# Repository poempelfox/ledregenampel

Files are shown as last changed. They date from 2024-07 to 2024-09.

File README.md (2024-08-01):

# LED-Regen-Ampel

## Intro

This is a small project that contains hardware design and
firmware for a small traffic-light-style display that shows
whether you can leave the house without getting wet. As it
utilizes regenampel.de to get the prediction, this is pretty
much useless outside of germany, which is why the rest of
the description is in german.

Haupt-Ziel dieses Projekts war es, mal eine Platine mit
richtig vielen LEDs drauf zu designen, um sie dann von einem
guenstigen Chinesischen Prototypenfertiger (JLCPCB) anfertigen
zu lassen.
Da ich ein Fan der [Regenampel](https://regenampel.de)
bin, kam die Idee auf, eine aus ganz vielen LEDs bestehende
Regenampel zu konstruieren, in einer Groesse die man bequem
neben die Wohnungstuer oder auch die Tuer des [ZAM](https://zam.haus)
haengen kann.

## Hardware Beschreibung Grob-Uebersicht

* ca. 21 x 7,5 cm grosse Platine
* Rot / Gelb / Gruen bestehend aus je 51 in konzentrischen Kreisen
  angeordneten LEDs (keine superhellen, generische in 0805 Gehaeuse),
  Durchmesser 5 cm.
* kleines OLED-Display unter der Ampel, um den Zusatztext den die
  Regenampel in manchen Situationen liefert (Beispiel: "Noch 20 Minuten
  starker Niederschlag") anzeigen zu koennen.
* Ein WaveShare ESP32-C3-Zero dient als zentrale Steuerung. Er wird
  auf die Rueckseite geloetet.
* Der ESP32-C3 steuert die LEDs ueber je einen MOSFET pro Farbe
  mit einem dedizierten I/O-Pin pro Farbe. Die Helligkeit kann dabei
  fuer jede Farbe einzeln ueber PWM mit 4096 Stufen geregelt werden.
  Das OLED wird ueber I2C angesprochen.
* momentaner Status: Hardware wurde geliefert und funktioniert zumindest
  teilweise.

## Hardware-Beschreibung Detail

Die Platine wurde in KiCad entworfen.
Die KiCad-Dateien finden sich im Unterverzeichnis [kicad/](kicad/).

Um die Platine nachbauen zu lassen, braucht man moeglicherweise
nichtmal KiCad zu oeffnen: Denn im Unterverzeichnis
[kicad/ledregenampel/jlcpcb/production_files/](kicad/ledregenampel/jlcpcb/production_files/)
finden sich die drei Dateien, die JLCPCB benoetigt um die Platine
zu fertigen: Das gerber-.zip, die BOM (Bill Of Materials), und das
CPL (Component PLacement). Verwendet wurde das, was im Juli 2024
dort auf Lager war. Solltet ihr zu einem spaeteren Zeitpunkt versuchen
das auch fertigen zu lassen, koennte es natuerlich sein dass Teile
nicht auf Lager sind und ersetzt werden muessen. Anders formuliert: YMMV.

Neben der gefertigten Platine sind nur zwei zusaetzliche Teile
notwendig:

* WaveShare ESP32-C3-Zero. Ein Microcontroller mit castellated mounting
  holes, so dass man ihn ohne Gefummel mit Buchsen- und Stiftleisten
  einfach auf die Rueckseite der Platine loeten kann. Der C3 ist zum
  Zeitpunkt dieses Projekts einer der kleinsten (und billigsten)
  Microcontroller die Espressif anbietet, fuer die ihm hier zugedachten
  Aufgaben aber immer noch deutlich ueberdimensioniert. Auf der
  Waveshare-Platine befindet sich u.a. eine USB-C-Buchse und ein
  Spannungsregler (Linearregler :-/) fuer die 3.3V.
* [Ein von TinyTronics bezogenes 2.08 inch OLED-Display mit 256x64 Pixeln](https://www.tinytronics.nl/en/displays/oled/2.08-inch-oled-display-256*64-pixels-white-i2c). Ich hatte
  ernsthafte Probleme, ein meinen Anforderungen nach "nicht winzig, I2C,
  extra-wide, 3.3V" entsprechendes Display zu finden, das war eines der
  wenigen passenden Angebote. Es handelt sich um ein Display
  des zumindest mir voellig unbekannten Herstellers "ZHONGJINGYUAN"
  mit einem SHT1122 Controller. Das Display wird ueber I2C
  angesprochen. Es wird auf die Vorderseite der LED-Regenampel-
  Platine geloetet.

Die USB-C-Buchse auf dem ESP32-Board ist der normale Weg, um
das Projekt mit Strom zu versorgen. USB-Power und "5V" Schiene
auf der Platine sind dabei einfach durchverbunden, d.h. es darf
falls auf andere Weise 5V eingespeist werden KEINESFALLS
gleichzeitig USB-C verbunden werden. Es ist ausserdem zu
beachten, dass der erwartete Stromverbrauch einer einzigen
Ampelfarbe bei 100% Helligkeit um 1A liegt. Es empfiehlt sich
also nicht, mehrere Ampelfarben gleichzeitig mit hoher
Helligkeit leuchten zu lassen.

Uebrigens sind 100% Helligkeit generell nicht der intendierte
Betriebsmodus. Mal abgesehen von dem geringfuegigen Problem,
dass das vermutlich den Betrachter der Ampel blind machen
wuerde, ist auch die dabei entstehende Abwaerme enorm -
die Platine wuerde wahrscheinlich recht schnell ueberhitzen.
"Normal" ist PWM mit unter 20% duty cycle...

## Hardware - known bugs

* Der ESP32-C3 wurde bei ersten Vorabtests alleine unangenehm
  heiss. Das ist laut "Internet" normal, und laut Specs darf
  der Chip auch bis zu 105 Grad. Nach dem aufloeten der Waveshare-
  Platine auf die grosse Platine scheint jedoch die
  Waerme sehr gut an die grosse Platine abgegeben zu werden,
  es ist kein nennenswerter Waermeherd mehr feststellbar.
* Die Loecher fuer das I2C-Display sind etwas arg klein geraten.
  Es passt gerade noch so, hat aber merklichen Widerstand beim
  einstecken der Display-Pins, und ist unschoen zu loeten.
  Dieser Fehler wurde im KiCad-.pcb-File bereits behoben.

## Firmware

* basiert auf der foxesptemp-Firmware.
* hat ein Admin-Webinterface, ueber das der angezeigte Ort (bzw. Weg)
  und die Helligkeit der Ampelfarben eingestellt werden kann.
* Hinweis: Der C3 wird anders programmiert als die meisten
  ESPs, es gibt naemlich keinen USB-seriell-Adapter auf der
  winzigen Platine. Stattdessen muss man: USB mit dem Rechner
  verbinden, dann den "Boot"-Knopf gedrueckt halten, dann
  kurz "Reset" druecken, dann kann man nach ein paar
  Sekunden "Boot" wieder loslassen. Dadurch geht der Chip
  in den Programmiermodus, der Bootloader emuliert einen
  USB-Seriell-Adapter, und man kann ihn wie gewohnt
  ueber idf.py flashen. Auch den Reset am Ende des Flashens
  muss man allerdings manuell machen, wieder ueber
  Knopfdruck. Gluecklicherweise muss man dieses komplexe
  Procedere nur ein mal zur Erstbefuellung durchfuehren:
  Die ledregenampel-firmware unterstuetzt Online-Firmware-
  Update ueber ihr Webinterface...

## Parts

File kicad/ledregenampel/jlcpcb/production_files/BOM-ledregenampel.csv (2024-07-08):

Comment | Designator | Footprint | LCSC
C1 | 100nF | C_0402_1005Metric | C1525 | 26786529 | 0 | 0
C2 | 100uF | C_1206_3216Metric | C15008 | 1087743 | 0 | 0
C3 | 100uF | C_1206_3216Metric | C15008 | 1087743 | 0 | 0
C4 | 100uF | C_1206_3216Metric | C15008 | 1087743 | 0 | 0
C5 | 100uF | C_1206_3216Metric | C15008 | 1087743 | 0 | 0
C6 | 100nF | C_0402_1005Metric | C1525 | 26786529 | 0 | 0
D1 | LED G | LED_0805_2012Metric | C688883 | 15123 | 0 | 0
D10 | LED G | LED_0805_2012Metric | C688883 | 15123 | 0 | 0
D100 | LED Y | LED_0805_2012Metric | C779458 | 3875 | 0 | 0
D101 | LED Y | LED_0805_2012Metric | C779458 | 3875 | 0 | 0
D102 | LED Y | LED_0805_2012Metric | C779458 | 3875 | 0 | 0
D103 | LED R | LED_0805_2012Metric | C688884 | 23736 | 0 | 0
D104 | LED R | LED_0805_2012Metric | C688884 | 23736 | 0 | 0
D105 | LED R | LED_0805_2012Metric | C688884 | 23736 | 0 | 0
D106 | LED R | LED_0805_2012Metric | C688884 | 23736 | 0 | 0
D107 | LED R | LED_0805_2012Metric | C688884 | 23736 | 0 | 0
D108 | LED R | LED_0805_2012Metric | C688884 | 23736 | 0 | 0
D109 | LED R | LED_0805_2012Metric | C688884 | 23736 | 0 | 0
D11 | LED G | LED_0805_2012Metric | C688883 | 15123 | 0 | 0
D110 | LED R | LED_0805_2012Metric | C688884 | 23736 | 0 | 0
D111 | LED R | LED_0805_2012Metric | C688884 | 23736 | 0 | 0
D112 | LED R | LED_0805_2012Metric | C688884 | 23736 | 0 | 0
D113 | LED R | LED_0805_2012Metric | C688884 | 23736 | 0 | 0
D114 | LED R | LED_0805_2012Metric | C688884 | 23736 | 0 | 0
D115 | LED R | LED_0805_2012Metric | C688884 | 23736 | 0 | 0
D116 | LED R | LED_0805_2012Metric | C688884 | 23736 | 0 | 0
D117 | LED R | LED_0805_2012Metric | C688884 | 23736 | 0 | 0
D118 | LED R | LED_0805_2012Metric | C688884 | 23736 | 0 | 0
D119 | LED R | LED_0805_2012Metric | C688884 | 23736 | 0 | 0
D12 | LED G | LED_0805_2012Metric | C688883 | 15123 | 0 | 0
D120 | LED R | LED_0805_2012Metric | C688884 | 23736 | 0 | 0
D121 | LED R | LED_0805_2012Metric | C688884 | 23736 | 0 | 0
D122 | LED R | LED_0805_2012Metric | C688884 | 23736 | 0 | 0
D123 | LED R | LED_0805_2012Metric | C688884 | 23736 | 0 | 0
D124 | LED R | LED_0805_2012Metric | C688884 | 23736 | 0 | 0
D125 | LED R | LED_0805_2012Metric | C688884 | 23736 | 0 | 0
D126 | LED R | LED_0805_2012Metric | C688884 | 23736 | 0 | 0
D127 | LED R | LED_0805_2012Metric | C688884 | 23736 | 0 | 0
D128 | LED R | LED_0805_2012Metric | C688884 | 23736 | 0 | 0
D129 | LED R | LED_0805_2012Metric | C688884 | 23736 | 0 | 0
D13 | LED G | LED_0805_2012Metric | C688883 | 15123 | 0 | 0
D130 | LED R | LED_0805_2012Metric | C688884 | 23736 | 0 | 0
D131 | LED R | LED_0805_2012Metric | C688884 | 23736 | 0 | 0
D132 | LED R | LED_0805_2012Metric | C688884 | 23736 | 0 | 0
D133 | LED R | LED_0805_2012Metric | C688884 | 23736 | 0 | 0
D134 | LED R | LED_0805_2012Metric | C688884 | 23736 | 0 | 0
D135 | LED R | LED_0805_2012Metric | C688884 | 23736 | 0 | 0
D136 | LED R | LED_0805_2012Metric | C688884 | 23736 | 0 | 0
D137 | LED R | LED_0805_2012Metric | C688884 | 23736 | 0 | 0
D138 | LED R | LED_0805_2012Metric | C688884 | 23736 | 0 | 0
D139 | LED R | LED_0805_2012Metric | C688884 | 23736 | 0 | 0
D14 | LED G | LED_0805_2012Metric | C688883 | 15123 | 0 | 0
D140 | LED R | LED_0805_2012Metric | C688884 | 23736 | 0 | 0
D141 | LED R | LED_0805_2012Metric | C688884 | 23736 | 0 | 0
D142 | LED R | LED_0805_2012Metric | C688884 | 23736 | 0 | 0
D143 | LED R | LED_0805_2012Metric | C688884 | 23736 | 0 | 0
D144 | LED R | LED_0805_2012Metric | C688884 | 23736 | 0 | 0
D145 | LED R | LED_0805_2012Metric | C688884 | 23736 | 0 | 0
D146 | LED R | LED_0805_2012Metric | C688884 | 23736 | 0 | 0
D147 | LED R | LED_0805_2012Metric | C688884 | 23736 | 0 | 0
D148 | LED R | LED_0805_2012Metric | C688884 | 23736 | 0 | 0
D149 | LED R | LED_0805_2012Metric | C688884 | 23736 | 0 | 0
D15 | LED G | LED_0805_2012Metric | C688883 | 15123 | 0 | 0
D150 | LED R | LED_0805_2012Metric | C688884 | 23736 | 0 | 0
D151 | LED R | LED_0805_2012Metric | C688884 | 23736 | 0 | 0
D152 | LED R | LED_0805_2012Metric | C688884 | 23736 | 0 | 0
D153 | LED R | LED_0805_2012Metric | C688884 | 23736 | 0 | 0
D16 | LED G | LED_0805_2012Metric | C688883 | 15123 | 0 | 0
D17 | LED G | LED_0805_2012Metric | C688883 | 15123 | 0 | 0
D18 | LED G | LED_0805_2012Metric | C688883 | 15123 | 0 | 0
D19 | LED G | LED_0805_2012Metric | C688883 | 15123 | 0 | 0
D2 | LED G | LED_0805_2012Metric | C688883 | 15123 | 0 | 0
D20 | LED G | LED_0805_2012Metric | C688883 | 15123 | 0 | 0
D21 | LED G | LED_0805_2012Metric | C688883 | 15123 | 0 | 0
D22 | LED G | LED_0805_2012Metric | C688883 | 15123 | 0 | 0
D23 | LED G | LED_0805_2012Metric | C688883 | 15123 | 0 | 0
D24 | LED G | LED_0805_2012Metric | C688883 | 15123 | 0 | 0
D25 | LED G | LED_0805_2012Metric | C688883 | 15123 | 0 | 0
D26 | LED G | LED_0805_2012Metric | C688883 | 15123 | 0 | 0
D27 | LED G | LED_0805_2012Metric | C688883 | 15123 | 0 | 0
D28 | LED G | LED_0805_2012Metric | C688883 | 15123 | 0 | 0
D29 | LED G | LED_0805_2012Metric | C688883 | 15123 | 0 | 0
D3 | LED G | LED_0805_2012Metric | C688883 | 15123 | 0 | 0
D30 | LED G | LED_0805_2012Metric | C688883 | 15123 | 0 | 0
D31 | LED G | LED_0805_2012Metric | C688883 | 15123 | 0 | 0
D32 | LED G | LED_0805_2012Metric | C688883 | 15123 | 0 | 0
D33 | LED G | LED_0805_2012Metric | C688883 | 15123 | 0 | 0
D34 | LED G | LED_0805_2012Metric | C688883 | 15123 | 0 | 0
D35 | LED G | LED_0805_2012Metric | C688883 | 15123 | 0 | 0
D36 | LED G | LED_0805_2012Metric | C688883 | 15123 | 0 | 0
D37 | LED G | LED_0805_2012Metric | C688883 | 15123 | 0 | 0
D38 | LED G | LED_0805_2012Metric | C688883 | 15123 | 0 | 0
D39 | LED G | LED_0805_2012Metric | C688883 | 15123 | 0 | 0
D4 | LED G | LED_0805_2012Metric | C688883 | 15123 | 0 | 0
D40 | LED G | LED_0805_2012Metric | C688883 | 15123 | 0 | 0
D41 | LED G | LED_0805_2012Metric | C688883 | 15123 | 0 | 0
D42 | LED G | LED_0805_2012Metric | C688883 | 15123 | 0 | 0
D43 | LED G | LED_0805_2012Metric | C688883 | 15123 | 0 | 0
D44 | LED G | LED_0805_2012Metric | C688883 | 15123 | 0 | 0
D45 | LED G | LED_0805_2012Metric | C688883 | 15123 | 0 | 0
D46 | LED G | LED_0805_2012Metric | C688883 | 15123 | 0 | 0
D47 | LED G | LED_0805_2012Metric | C688883 | 15123 | 0 | 0
D48 | LED G | LED_0805_2012Metric | C688883 | 15123 | 0 | 0
D49 | LED G | LED_0805_2012Metric | C688883 | 15123 | 0 | 0
D5 | LED G | LED_0805_2012Metric | C688883 | 15123 | 0 | 0
D50 | LED G | LED_0805_2012Metric | C688883 | 15123 | 0 | 0
D51 | LED G | LED_0805_2012Metric | C688883 | 15123 | 0 | 0
D52 | LED Y | LED_0805_2012Metric | C779458 | 3875 | 0 | 0
D53 | LED Y | LED_0805_2012Metric | C779458 | 3875 | 0 | 0
D54 | LED Y | LED_0805_2012Metric | C779458 | 3875 | 0 | 0
D55 | LED Y | LED_0805_2012Metric | C779458 | 3875 | 0 | 0
D56 | LED Y | LED_0805_2012Metric | C779458 | 3875 | 0 | 0
D57 | LED Y | LED_0805_2012Metric | C779458 | 3875 | 0 | 0
D58 | LED Y | LED_0805_2012Metric | C779458 | 3875 | 0 | 0
D59 | LED Y | LED_0805_2012Metric | C779458 | 3875 | 0 | 0
D6 | LED G | LED_0805_2012Metric | C688883 | 15123 | 0 | 0
D60 | LED Y | LED_0805_2012Metric | C779458 | 3875 | 0 | 0
D61 | LED Y | LED_0805_2012Metric | C779458 | 3875 | 0 | 0
D62 | LED Y | LED_0805_2012Metric | C779458 | 3875 | 0 | 0
D63 | LED Y | LED_0805_2012Metric | C779458 | 3875 | 0 | 0
D64 | LED Y | LED_0805_2012Metric | C779458 | 3875 | 0 | 0
D65 | LED Y | LED_0805_2012Metric | C779458 | 3875 | 0 | 0
D66 | LED Y | LED_0805_2012Metric | C779458 | 3875 | 0 | 0
D67 | LED Y | LED_0805_2012Metric | C779458 | 3875 | 0 | 0
D68 | LED Y | LED_0805_2012Metric | C779458 | 3875 | 0 | 0
D69 | LED Y | LED_0805_2012Metric | C779458 | 3875 | 0 | 0
D7 | LED G | LED_0805_2012Metric | C688883 | 15123 | 0 | 0
D70 | LED Y | LED_0805_2012Metric | C779458 | 3875 | 0 | 0
D71 | LED Y | LED_0805_2012Metric | C779458 | 3875 | 0 | 0
D72 | LED Y | LED_0805_2012Metric | C779458 | 3875 | 0 | 0
D73 | LED Y | LED_0805_2012Metric | C779458 | 3875 | 0 | 0
D74 | LED Y | LED_0805_2012Metric | C779458 | 3875 | 0 | 0
D75 | LED Y | LED_0805_2012Metric | C779458 | 3875 | 0 | 0
D76 | LED Y | LED_0805_2012Metric | C779458 | 3875 | 0 | 0
D77 | LED Y | LED_0805_2012Metric | C779458 | 3875 | 0 | 0
D78 | LED Y | LED_0805_2012Metric | C779458 | 3875 | 0 | 0
D79 | LED Y | LED_0805_2012Metric | C779458 | 3875 | 0 | 0
D8 | LED G | LED_0805_2012Metric | C688883 | 15123 | 0 | 0
D80 | LED Y | LED_0805_2012Metric | C779458 | 3875 | 0 | 0
D81 | LED Y | LED_0805_2012Metric | C779458 | 3875 | 0 | 0
D82 | LED Y | LED_0805_2012Metric | C779458 | 3875 | 0 | 0
D83 | LED Y | LED_0805_2012Metric | C779458 | 3875 | 0 | 0
D84 | LED Y | LED_0805_2012Metric | C779458 | 3875 | 0 | 0
D85 | LED Y | LED_0805_2012Metric | C779458 | 3875 | 0 | 0
D86 | LED Y | LED_0805_2012Metric | C779458 | 3875 | 0 | 0
D87 | LED Y | LED_0805_2012Metric | C779458 | 3875 | 0 | 0
D88 | LED Y | LED_0805_2012Metric | C779458 | 3875 | 0 | 0
D89 | LED Y | LED_0805_2012Metric | C779458 | 3875 | 0 | 0
D9 | LED G | LED_0805_2012Metric | C688883 | 15123 | 0 | 0
D90 | LED Y | LED_0805_2012Metric | C779458 | 3875 | 0 | 0
D91 | LED Y | LED_0805_2012Metric | C779458 | 3875 | 0 | 0
D92 | LED Y | LED_0805_2012Metric | C779458 | 3875 | 0 | 0
D93 | LED Y | LED_0805_2012Metric | C779458 | 3875 | 0 | 0
D94 | LED Y | LED_0805_2012Metric | C779458 | 3875 | 0 | 0
D95 | LED Y | LED_0805_2012Metric | C779458 | 3875 | 0 | 0
D96 | LED Y | LED_0805_2012Metric | C779458 | 3875 | 0 | 0
D97 | LED Y | LED_0805_2012Metric | C779458 | 3875 | 0 | 0
D98 | LED Y | LED_0805_2012Metric | C779458 | 3875 | 0 | 0
D99 | LED Y | LED_0805_2012Metric | C779458 | 3875 | 0 | 0
Q1 | AO3400A | SOT-23 | C20917 | 628525 | 0 | 0
Q2 | AO3400A | SOT-23 | C20917 | 628525 | 0 | 0
Q3 | AO3400A | SOT-23 | C20917 | 628525 | 0 | 0
R1 | 120Ω | R_0402_modsilkscreen | C25079 | 547006 | 0 | 0
R10 | 120Ω | R_0402_modsilkscreen | C25079 | 547006 | 0 | 0
R100 | 150Ω | R_0402_modsilkscreen | C25143 | 39000 | 0 | 0
R101 | 150Ω | R_0402_modsilkscreen | C25143 | 39000 | 0 | 0
R102 | 150Ω | R_0402_modsilkscreen | C25143 | 39000 | 0 | 0
R103 | 150Ω | R_0402_modsilkscreen | C25143 | 39000 | 0 | 0
R104 | 150Ω | R_0402_modsilkscreen | C25143 | 39000 | 0 | 0
R105 | 150Ω | R_0402_modsilkscreen | C25143 | 39000 | 0 | 0
R106 | 150Ω | R_0402_modsilkscreen | C25143 | 39000 | 0 | 0
R107 | 150Ω | R_0402_modsilkscreen | C25143 | 39000 | 0 | 0
R108 | 150Ω | R_0402_modsilkscreen | C25143 | 39000 | 0 | 0
R109 | 150Ω | R_0402_modsilkscreen | C25143 | 39000 | 0 | 0
R11 | 120Ω | R_0402_modsilkscreen | C25079 | 547006 | 0 | 0
R110 | 150Ω | R_0402_modsilkscreen | C25143 | 39000 | 0 | 0
R111 | 150Ω | R_0402_modsilkscreen | C25143 | 39000 | 0 | 0
R112 | 150Ω | R_0402_modsilkscreen | C25143 | 39000 | 0 | 0
R113 | 150Ω | R_0402_modsilkscreen | C25143 | 39000 | 0 | 0
R114 | 150Ω | R_0402_modsilkscreen | C25143 | 39000 | 0 | 0
R115 | 150Ω | R_0402_modsilkscreen | C25143 | 39000 | 0 | 0
R116 | 150Ω | R_0402_modsilkscreen | C25143 | 39000 | 0 | 0
R117 | 150Ω | R_0402_modsilkscreen | C25143 | 39000 | 0 | 0
R118 | 150Ω | R_0402_modsilkscreen | C25143 | 39000 | 0 | 0
R119 | 150Ω | R_0402_modsilkscreen | C25143 | 39000 | 0 | 0
R12 | 120Ω | R_0402_modsilkscreen | C25079 | 547006 | 0 | 0
R120 | 150Ω | R_0402_modsilkscreen | C25143 | 39000 | 0 | 0
R121 | 150Ω | R_0402_modsilkscreen | C25143 | 39000 | 0 | 0
R122 | 150Ω | R_0402_modsilkscreen | C25143 | 39000 | 0 | 0
R123 | 150Ω | R_0402_modsilkscreen | C25143 | 39000 | 0 | 0
R124 | 150Ω | R_0402_modsilkscreen | C25143 | 39000 | 0 | 0
R125 | 150Ω | R_0402_modsilkscreen | C25143 | 39000 | 0 | 0
R126 | 150Ω | R_0402_modsilkscreen | C25143 | 39000 | 0 | 0
R127 | 150Ω | R_0402_modsilkscreen | C25143 | 39000 | 0 | 0
R128 | 150Ω | R_0402_modsilkscreen | C25143 | 39000 | 0 | 0
R129 | 150Ω | R_0402_modsilkscreen | C25143 | 39000 | 0 | 0
R13 | 120Ω | R_0402_modsilkscreen | C25079 | 547006 | 0 | 0
R130 | 150Ω | R_0402_modsilkscreen | C25143 | 39000 | 0 | 0
R131 | 150Ω | R_0402_modsilkscreen | C25143 | 39000 | 0 | 0
R132 | 150Ω | R_0402_modsilkscreen | C25143 | 39000 | 0 | 0
R133 | 150Ω | R_0402_modsilkscreen | C25143 | 39000 | 0 | 0
R134 | 150Ω | R_0402_modsilkscreen | C25143 | 39000 | 0 | 0
R135 | 150Ω | R_0402_modsilkscreen | C25143 | 39000 | 0 | 0
R136 | 150Ω | R_0402_modsilkscreen | C25143 | 39000 | 0 | 0
R137 | 150Ω | R_0402_modsilkscreen | C25143 | 39000 | 0 | 0
R138 | 150Ω | R_0402_modsilkscreen | C25143 | 39000 | 0 | 0
R139 | 150Ω | R_0402_modsilkscreen | C25143 | 39000 | 0 | 0
R14 | 120Ω | R_0402_modsilkscreen | C25079 | 547006 | 0 | 0
R140 | 150Ω | R_0402_modsilkscreen | C25143 | 39000 | 0 | 0
R141 | 150Ω | R_0402_modsilkscreen | C25143 | 39000 | 0 | 0
R142 | 150Ω | R_0402_modsilkscreen | C25143 | 39000 | 0 | 0
R143 | 150Ω | R_0402_modsilkscreen | C25143 | 39000 | 0 | 0
R144 | 150Ω | R_0402_modsilkscreen | C25143 | 39000 | 0 | 0
R145 | 150Ω | R_0402_modsilkscreen | C25143 | 39000 | 0 | 0
R146 | 150Ω | R_0402_modsilkscreen | C25143 | 39000 | 0 | 0
R147 | 150Ω | R_0402_modsilkscreen | C25143 | 39000 | 0 | 0
R148 | 150Ω | R_0402_modsilkscreen | C25143 | 39000 | 0 | 0
R149 | 150Ω | R_0402_modsilkscreen | C25143 | 39000 | 0 | 0
R15 | 120Ω | R_0402_modsilkscreen | C25079 | 547006 | 0 | 0
R150 | 150Ω | R_0402_modsilkscreen | C25143 | 39000 | 0 | 0
R151 | 150Ω | R_0402_modsilkscreen | C25143 | 39000 | 0 | 0
R152 | 150Ω | R_0402_modsilkscreen | C25143 | 39000 | 0 | 0
R153 | 150Ω | R_0402_modsilkscreen | C25143 | 39000 | 0 | 0
R154 | 33Ω | R_0402_modsilkscreen | C25105 | 2829282 | 0 | 0
R155 | 33Ω | R_0402_modsilkscreen | C25105 | 2829282 | 0 | 0
R156 | 33Ω | R_0402_modsilkscreen | C25105 | 2829282 | 0 | 0
R157 | 1MΩ | R_0402_modsilkscreen | C26083 | 2594408 | 0 | 0
R158 | 1MΩ | R_0402_modsilkscreen | C26083 | 2594408 | 0 | 0
R159 | 1MΩ | R_0402_modsilkscreen | C26083 | 2594408 | 0 | 0
R16 | 120Ω | R_0402_modsilkscreen | C25079 | 547006 | 0 | 0
R17 | 120Ω | R_0402_modsilkscreen | C25079 | 547006 | 0 | 0
R18 | 120Ω | R_0402_modsilkscreen | C25079 | 547006 | 0 | 0
R19 | 120Ω | R_0402_modsilkscreen | C25079 | 547006 | 0 | 0
R2 | 120Ω | R_0402_modsilkscreen | C25079 | 547006 | 0 | 0
R20 | 120Ω | R_0402_modsilkscreen | C25079 | 547006 | 0 | 0
R21 | 120Ω | R_0402_modsilkscreen | C25079 | 547006 | 0 | 0
R22 | 120Ω | R_0402_modsilkscreen | C25079 | 547006 | 0 | 0
R23 | 120Ω | R_0402_modsilkscreen | C25079 | 547006 | 0 | 0
R24 | 120Ω | R_0402_modsilkscreen | C25079 | 547006 | 0 | 0
R25 | 120Ω | R_0402_modsilkscreen | C25079 | 547006 | 0 | 0
R26 | 120Ω | R_0402_modsilkscreen | C25079 | 547006 | 0 | 0
R27 | 120Ω | R_0402_modsilkscreen | C25079 | 547006 | 0 | 0
R28 | 120Ω | R_0402_modsilkscreen | C25079 | 547006 | 0 | 0
R29 | 120Ω | R_0402_modsilkscreen | C25079 | 547006 | 0 | 0
R3 | 120Ω | R_0402_modsilkscreen | C25079 | 547006 | 0 | 0
R30 | 120Ω | R_0402_modsilkscreen | C25079 | 547006 | 0 | 0
R31 | 120Ω | R_0402_modsilkscreen | C25079 | 547006 | 0 | 0
R32 | 120Ω | R_0402_modsilkscreen | C25079 | 547006 | 0 | 0
R33 | 120Ω | R_0402_modsilkscreen | C25079 | 547006 | 0 | 0
R34 | 120Ω | R_0402_modsilkscreen | C25079 | 547006 | 0 | 0
R35 | 120Ω | R_0402_modsilkscreen | C25079 | 547006 | 0 | 0
R36 | 120Ω | R_0402_modsilkscreen | C25079 | 547006 | 0 | 0
R37 | 120Ω | R_0402_modsilkscreen | C25079 | 547006 | 0 | 0
R38 | 120Ω | R_0402_modsilkscreen | C25079 | 547006 | 0 | 0
R39 | 120Ω | R_0402_modsilkscreen | C25079 | 547006 | 0 | 0
R4 | 120Ω | R_0402_modsilkscreen | C25079 | 547006 | 0 | 0
R40 | 120Ω | R_0402_modsilkscreen | C25079 | 547006 | 0 | 0
R41 | 120Ω | R_0402_modsilkscreen | C25079 | 547006 | 0 | 0
R42 | 120Ω | R_0402_modsilkscreen | C25079 | 547006 | 0 | 0
R43 | 120Ω | R_0402_modsilkscreen | C25079 | 547006 | 0 | 0
R44 | 120Ω | R_0402_modsilkscreen | C25079 | 547006 | 0 | 0
R45 | 120Ω | R_0402_modsilkscreen | C25079 | 547006 | 0 | 0
R46 | 120Ω | R_0402_modsilkscreen | C25079 | 547006 | 0 | 0
R47 | 120Ω | R_0402_modsilkscreen | C25079 | 547006 | 0 | 0
R48 | 120Ω | R_0402_modsilkscreen | C25079 | 547006 | 0 | 0
R49 | 120Ω | R_0402_modsilkscreen | C25079 | 547006 | 0 | 0
R5 | 120Ω | R_0402_modsilkscreen | C25079 | 547006 | 0 | 0
R50 | 120Ω | R_0402_modsilkscreen | C25079 | 547006 | 0 | 0
R51 | 120Ω | R_0402_modsilkscreen | C25079 | 547006 | 0 | 0
R52 | 150Ω | R_0402_modsilkscreen | C25143 | 39000 | 0 | 0
R53 | 150Ω | R_0402_modsilkscreen | C25143 | 39000 | 0 | 0
R54 | 150Ω | R_0402_modsilkscreen | C25143 | 39000 | 0 | 0
R55 | 150Ω | R_0402_modsilkscreen | C25143 | 39000 | 0 | 0
R56 | 150Ω | R_0402_modsilkscreen | C25143 | 39000 | 0 | 0
R57 | 150Ω | R_0402_modsilkscreen | C25143 | 39000 | 0 | 0
R58 | 150Ω | R_0402_modsilkscreen | C25143 | 39000 | 0 | 0
R59 | 150Ω | R_0402_modsilkscreen | C25143 | 39000 | 0 | 0
R6 | 120Ω | R_0402_modsilkscreen | C25079 | 547006 | 0 | 0
R60 | 150Ω | R_0402_modsilkscreen | C25143 | 39000 | 0 | 0
R61 | 150Ω | R_0402_modsilkscreen | C25143 | 39000 | 0 | 0
R62 | 150Ω | R_0402_modsilkscreen | C25143 | 39000 | 0 | 0
R63 | 150Ω | R_0402_modsilkscreen | C25143 | 39000 | 0 | 0
R64 | 150Ω | R_0402_modsilkscreen | C25143 | 39000 | 0 | 0
R65 | 150Ω | R_0402_modsilkscreen | C25143 | 39000 | 0 | 0
R66 | 150Ω | R_0402_modsilkscreen | C25143 | 39000 | 0 | 0
R67 | 150Ω | R_0402_modsilkscreen | C25143 | 39000 | 0 | 0
R68 | 150Ω | R_0402_modsilkscreen | C25143 | 39000 | 0 | 0
R69 | 150Ω | R_0402_modsilkscreen | C25143 | 39000 | 0 | 0
R7 | 120Ω | R_0402_modsilkscreen | C25079 | 547006 | 0 | 0
R70 | 150Ω | R_0402_modsilkscreen | C25143 | 39000 | 0 | 0
R71 | 150Ω | R_0402_modsilkscreen | C25143 | 39000 | 0 | 0
R72 | 150Ω | R_0402_modsilkscreen | C25143 | 39000 | 0 | 0
R73 | 150Ω | R_0402_modsilkscreen | C25143 | 39000 | 0 | 0
R74 | 150Ω | R_0402_modsilkscreen | C25143 | 39000 | 0 | 0
R75 | 150Ω | R_0402_modsilkscreen | C25143 | 39000 | 0 | 0
R76 | 150Ω | R_0402_modsilkscreen | C25143 | 39000 | 0 | 0
R77 | 150Ω | R_0402_modsilkscreen | C25143 | 39000 | 0 | 0
R78 | 150Ω | R_0402_modsilkscreen | C25143 | 39000 | 0 | 0
R79 | 150Ω | R_0402_modsilkscreen | C25143 | 39000 | 0 | 0
R8 | 120Ω | R_0402_modsilkscreen | C25079 | 547006 | 0 | 0
R80 | 150Ω | R_0402_modsilkscreen | C25143 | 39000 | 0 | 0
R81 | 150Ω | R_0402_modsilkscreen | C25143 | 39000 | 0 | 0
R82 | 150Ω | R_0402_modsilkscreen | C25143 | 39000 | 0 | 0
R83 | 150Ω | R_0402_modsilkscreen | C25143 | 39000 | 0 | 0
R84 | 150Ω | R_0402_modsilkscreen | C25143 | 39000 | 0 | 0
R85 | 150Ω | R_0402_modsilkscreen | C25143 | 39000 | 0 | 0
R86 | 150Ω | R_0402_modsilkscreen | C25143 | 39000 | 0 | 0
R87 | 150Ω | R_0402_modsilkscreen | C25143 | 39000 | 0 | 0
R88 | 150Ω | R_0402_modsilkscreen | C25143 | 39000 | 0 | 0
R89 | 150Ω | R_0402_modsilkscreen | C25143 | 39000 | 0 | 0
R9 | 120Ω | R_0402_modsilkscreen | C25079 | 547006 | 0 | 0
R90 | 150Ω | R_0402_modsilkscreen | C25143 | 39000 | 0 | 0
R91 | 150Ω | R_0402_modsilkscreen | C25143 | 39000 | 0 | 0
R92 | 150Ω | R_0402_modsilkscreen | C25143 | 39000 | 0 | 0
R93 | 150Ω | R_0402_modsilkscreen | C25143 | 39000 | 0 | 0
R94 | 150Ω | R_0402_modsilkscreen | C25143 | 39000 | 0 | 0
R95 | 150Ω | R_0402_modsilkscreen | C25143 | 39000 | 0 | 0
R96 | 150Ω | R_0402_modsilkscreen | C25143 | 39000 | 0 | 0
R97 | 150Ω | R_0402_modsilkscreen | C25143 | 39000 | 0 | 0
R98 | 150Ω | R_0402_modsilkscreen | C25143 | 39000 | 0 | 0
R99 | 150Ω | R_0402_modsilkscreen | C25143 | 39000 | 0 | 0

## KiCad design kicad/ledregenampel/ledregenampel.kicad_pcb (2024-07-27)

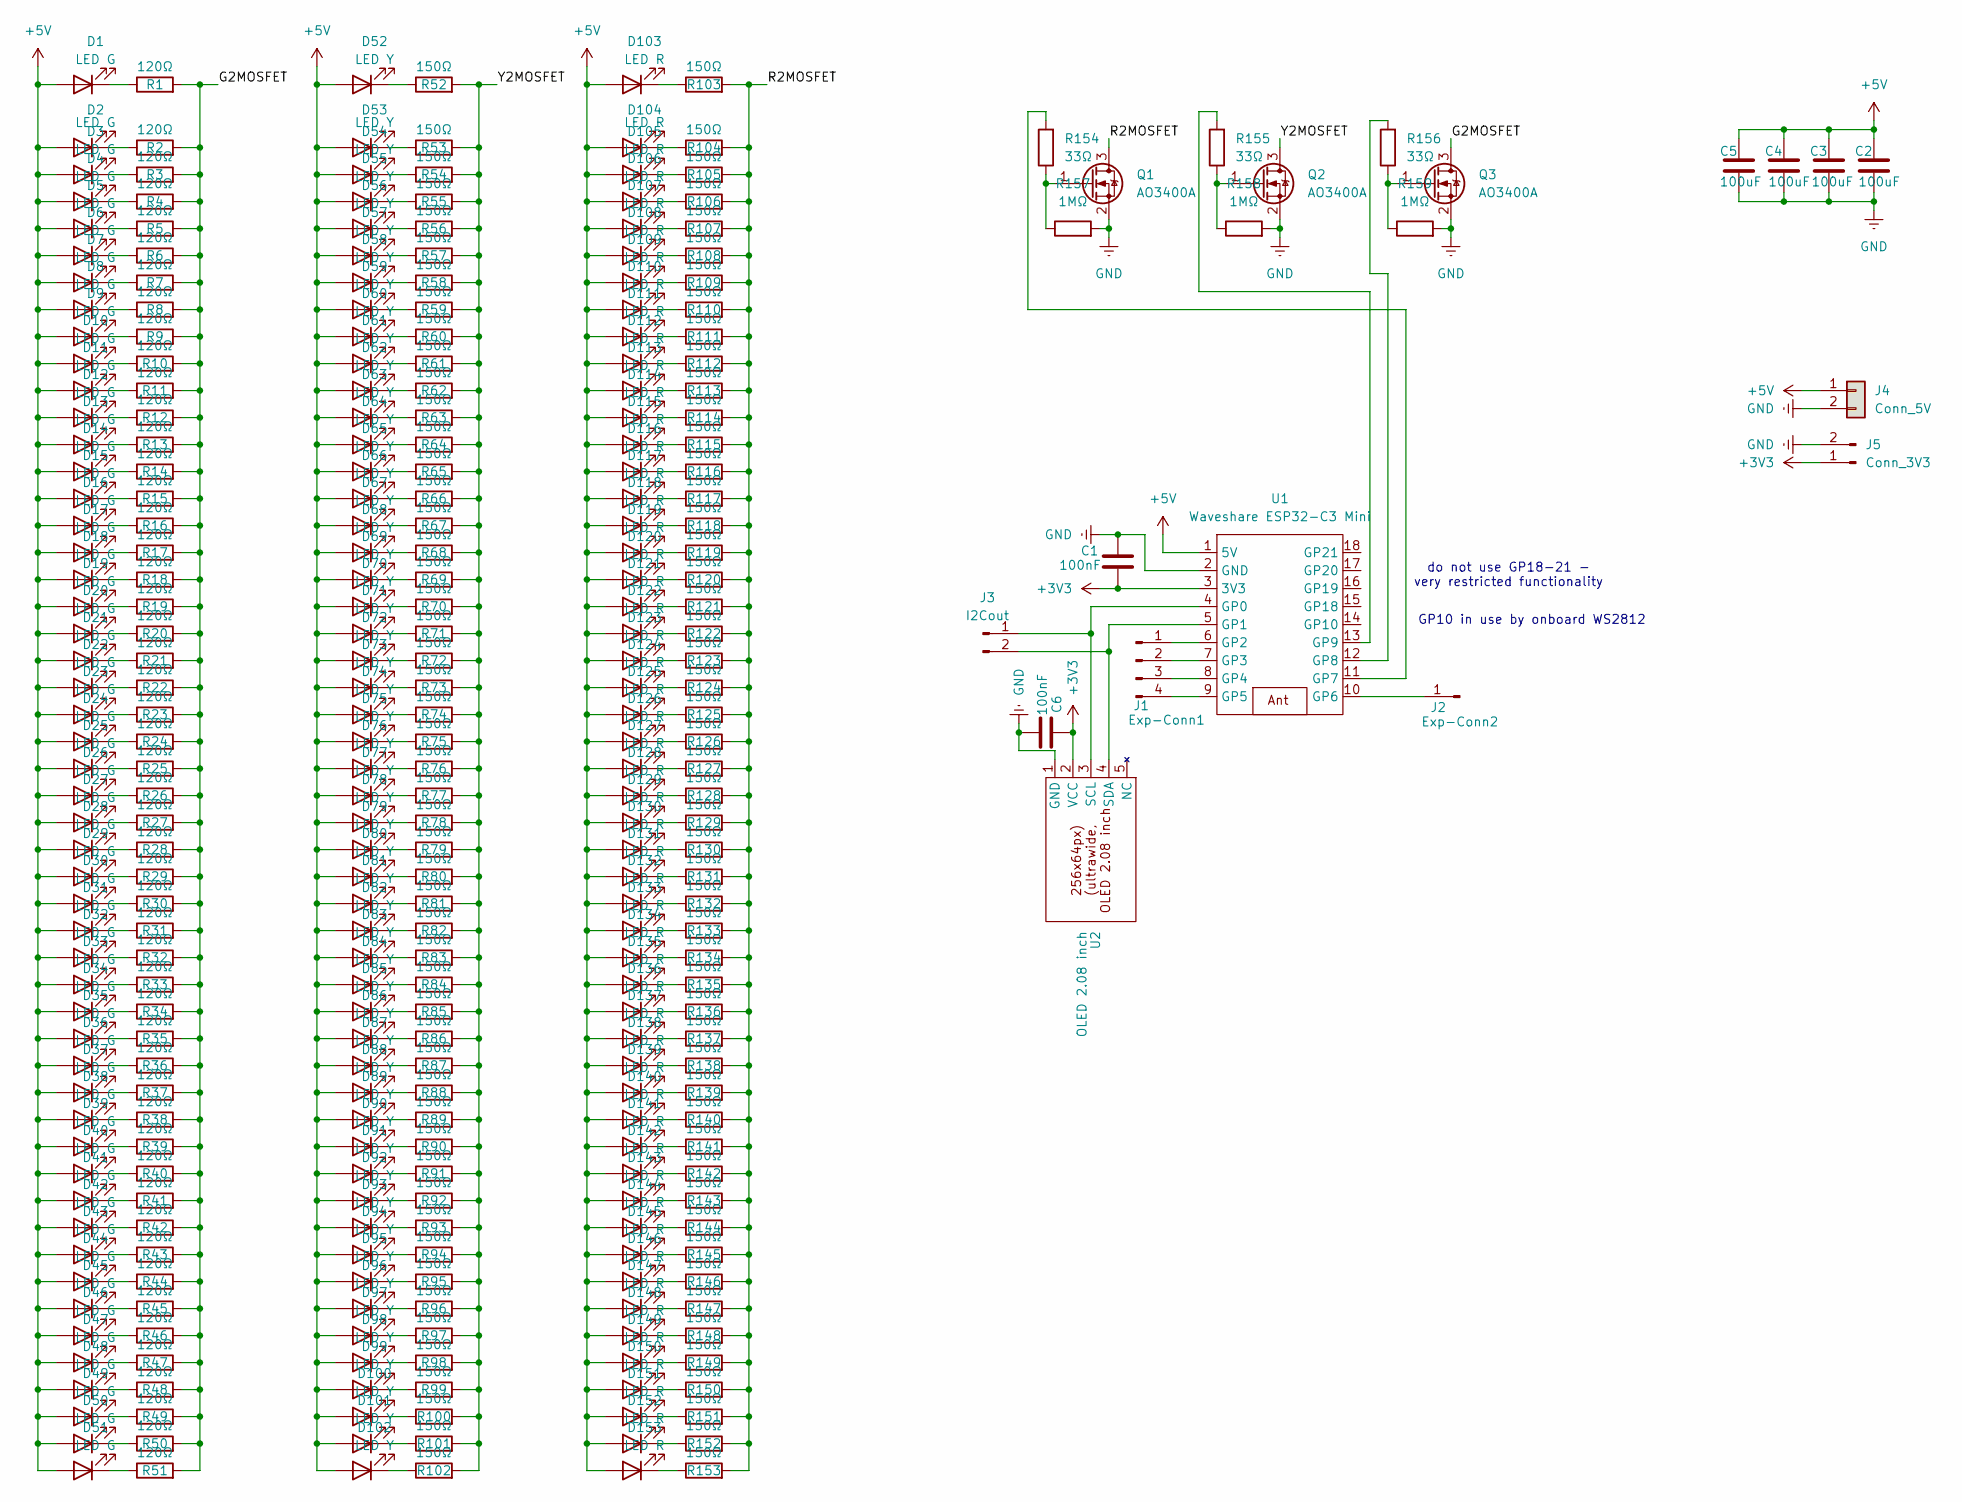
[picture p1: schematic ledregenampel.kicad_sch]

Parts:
C1, C6: 100nF; C_0402_1005Metric
C2, C3, C4, C5: 100uF; C_1206_3216Metric
D1, D2, D3, D4, D5, D6, D7, D8, D9, D10, D11, D12, D13, D14, D15, D16, D17, D18, D19, D20, D21, D22, D23, D24, D25, D26, D27, D28, D29, D30, D31, D32, D33, D34, D35, D36, D37, D38, D39, D40, D41, D42, D43, D44, D45, D46, D47, D48, D49, D50, D51: LED G; LED_0805_2012Metric
D52, D53, D54, D55, D56, D57, D58, D59, D60, D61, D62, D63, D64, D65, D66, D67, D68, D69, D70, D71, D72, D73, D74, D75, D76, D77, D78, D79, D80, D81, D82, D83, D84, D85, D86, D87, D88, D89, D90, D91, D92, D93, D94, D95, D96, D97, D98, D99, D100, D101, D102: LED Y; LED_0805_2012Metric
D103, D104, D105, D106, D107, D108, D109, D110, D111, D112, D113, D114, D115, D116, D117, D118, D119, D120, D121, D122, D123, D124, D125, D126, D127, D128, D129, D130, D131, D132, D133, D134, D135, D136, D137, D138, D139, D140, D141, D142, D143, D144, D145, D146, D147, D148, D149, D150, D151, D152, D153: LED R; LED_0805_2012Metric
J1: Exp-Conn1; PinHeader_1x04_P2.54mm_Vertical
J2: Exp-Conn2; PinHeader_1x01_P2.54mm_Vertical
J3: I2Cout; PinHeader_1x02_P2.54mm_Vertical
J4: Conn_5V; PinHeader_1x02_P2.54mm_Vertical
J5: Conn_3V3; PinHeader_1x02_P2.54mm_Vertical
Q1, Q2, Q3: AO3400A; SOT-23
R1, R2, R3, R4, R5, R6, R7, R8, R9, R10, R11, R12, R13, R14, R15, R16, R17, R18, R19, R20, R21, R22, R23, R24, R25, R26, R27, R28, R29, R30, R31, R32, R33, R34, R35, R36, R37, R38, R39, R40, R41, R42, R43, R44, R45, R46, R47, R48, R49, R50, R51: 120Ω; R_0402_modsilkscreen
R52, R53, R54, R55, R56, R57, R58, R59, R60, R61, R62, R63, R64, R65, R66, R67, R68, R69, R70, R71, R72, R73, R74, R75, R76, R77, R78, R79, R80, R81, R82, R83, R84, R85, R86, R87, R88, R89, R90, R91, R92, R93, R94, R95, R96, R97, R98, R99, R100, R101, R102, R103, R104, R105, R106, R107, R108, R109, R110, R111, R112, R113, R114, R115, R116, R117, R118, R119, R120, R121, R122, R123, R124, R125, R126, R127, R128, R129, R130, R131, R132, R133, R134, R135, R136, R137, R138, R139, R140, R141, R142, R143, R144, R145, R146, R147, R148, R149, R150, R151, R152, R153: 150Ω; R_0402_modsilkscreen
R154, R155, R156: 33Ω; R_0402_modsilkscreen
R157, R158, R159: 1MΩ; R_0402_modsilkscreen
U1: Waveshare ESP32-C3 Mini; Waveshare_ESP32-C3_Mini
U2: OLED 2.08 inch; OLED-2.08-inch

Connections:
+3V3: C1.1, C6.2, J5.1, U1.3 (3V3), U2.2 (VCC)
+5V: C2.1, C3.1, C4.1, C5.1, D1.2 (A), D2.2 (A), D3.2 (A), D4.2 (A), D5.2 (A), D6.2 (A), D7.2 (A), D8.2 (A), D9.2 (A), D10.2 (A), D11.2 (A), D12.2 (A), D13.2 (A), D14.2 (A), D15.2 (A), D16.2 (A), D17.2 (A), D18.2 (A), D19.2 (A), D20.2 (A), D21.2 (A), D22.2 (A), D23.2 (A), D24.2 (A), D25.2 (A), D26.2 (A), D27.2 (A), D28.2 (A), D29.2 (A), D30.2 (A), D31.2 (A), D32.2 (A), D33.2 (A), D34.2 (A), D35.2 (A), D36.2 (A), D37.2 (A), D38.2 (A), D39.2 (A), D40.2 (A), D41.2 (A), D42.2 (A), D43.2 (A), D44.2 (A), D45.2 (A), D46.2 (A), D47.2 (A), D48.2 (A), D49.2 (A), D50.2 (A), D51.2 (A), D52.2 (A), D53.2 (A), D54.2 (A), D55.2 (A), D56.2 (A), D57.2 (A), D58.2 (A), D59.2 (A), D60.2 (A), D61.2 (A), D62.2 (A), D63.2 (A), D64.2 (A), D65.2 (A), D66.2 (A), D67.2 (A), D68.2 (A), D69.2 (A), D70.2 (A), D71.2 (A), D72.2 (A), D73.2 (A), D74.2 (A), D75.2 (A), D76.2 (A), D77.2 (A), D78.2 (A), D79.2 (A), D80.2 (A), D81.2 (A), D82.2 (A), D83.2 (A), D84.2 (A), D85.2 (A), D86.2 (A), D87.2 (A), D88.2 (A), D89.2 (A), D90.2 (A), D91.2 (A), D92.2 (A), D93.2 (A), D94.2 (A), D95.2 (A), D96.2 (A), D97.2 (A), D98.2 (A), D99.2 (A), D100.2 (A), D101.2 (A), D102.2 (A), D103.2 (A), D104.2 (A), D105.2 (A), D106.2 (A), D107.2 (A), D108.2 (A), D109.2 (A), D110.2 (A), D111.2 (A), D112.2 (A), D113.2 (A), D114.2 (A), D115.2 (A), D116.2 (A), D117.2 (A), D118.2 (A), D119.2 (A), D120.2 (A), D121.2 (A), D122.2 (A), D123.2 (A), D124.2 (A), D125.2 (A), D126.2 (A), D127.2 (A), D128.2 (A), D129.2 (A), D130.2 (A), D131.2 (A), D132.2 (A), D133.2 (A), D134.2 (A), D135.2 (A), D136.2 (A), D137.2 (A), D138.2 (A), D139.2 (A), D140.2 (A), D141.2 (A), D142.2 (A), D143.2 (A), D144.2 (A), D145.2 (A), D146.2 (A), D147.2 (A), D148.2 (A), D149.2 (A), D150.2 (A), D151.2 (A), D152.2 (A), D153.2 (A), J4.1, U1.1 (5V)
/G2MOSFET: Q3.3 (D), R1.2, R2.2, R3.2, R4.2, R5.2, R6.2, R7.2, R8.2, R9.2, R10.2, R11.2, R12.2, R13.2, R14.2, R15.2, R16.2, R17.2, R18.2, R19.2, R20.2, R21.2, R22.2, R23.2, R24.2, R25.2, R26.2, R27.2, R28.2, R29.2, R30.2, R31.2, R32.2, R33.2, R34.2, R35.2, R36.2, R37.2, R38.2, R39.2, R40.2, R41.2, R42.2, R43.2, R44.2, R45.2, R46.2, R47.2, R48.2, R49.2, R50.2, R51.2
/R2MOSFET: Q1.3 (D), R103.2, R104.2, R105.2, R106.2, R107.2, R108.2, R109.2, R110.2, R111.2, R112.2, R113.2, R114.2, R115.2, R116.2, R117.2, R118.2, R119.2, R120.2, R121.2, R122.2, R123.2, R124.2, R125.2, R126.2, R127.2, R128.2, R129.2, R130.2, R131.2, R132.2, R133.2, R134.2, R135.2, R136.2, R137.2, R138.2, R139.2, R140.2, R141.2, R142.2, R143.2, R144.2, R145.2, R146.2, R147.2, R148.2, R149.2, R150.2, R151.2, R152.2, R153.2
/Y2MOSFET: Q2.3 (D), R52.2, R53.2, R54.2, R55.2, R56.2, R57.2, R58.2, R59.2, R60.2, R61.2, R62.2, R63.2, R64.2, R65.2, R66.2, R67.2, R68.2, R69.2, R70.2, R71.2, R72.2, R73.2, R74.2, R75.2, R76.2, R77.2, R78.2, R79.2, R80.2, R81.2, R82.2, R83.2, R84.2, R85.2, R86.2, R87.2, R88.2, R89.2, R90.2, R91.2, R92.2, R93.2, R94.2, R95.2, R96.2, R97.2, R98.2, R99.2, R100.2, R101.2, R102.2
GND: C1.2, C2.2, C3.2, C4.2, C5.2, C6.1, J4.2, J5.2, Q1.2 (S), Q2.2 (S), Q3.2 (S), R157.2, R158.2, R159.2, U1.2 (GND), U2.1 (GND)
unnamed: D1.1 (K), R1.1
unnamed: D2.1 (K), R2.1
unnamed: D3.1 (K), R3.1
unnamed: D4.1 (K), R4.1
unnamed: D5.1 (K), R5.1
unnamed: D6.1 (K), R6.1
unnamed: D7.1 (K), R7.1
unnamed: D8.1 (K), R8.1
unnamed: D9.1 (K), R9.1
unnamed: D10.1 (K), R10.1
unnamed: D11.1 (K), R11.1
unnamed: D12.1 (K), R12.1
unnamed: D13.1 (K), R13.1
unnamed: D14.1 (K), R14.1
unnamed: D15.1 (K), R15.1
unnamed: D16.1 (K), R16.1
unnamed: D17.1 (K), R17.1
unnamed: D18.1 (K), R18.1
unnamed: D19.1 (K), R19.1
unnamed: D20.1 (K), R20.1
unnamed: D21.1 (K), R21.1
unnamed: D22.1 (K), R22.1
unnamed: D23.1 (K), R23.1
unnamed: D24.1 (K), R24.1
unnamed: D25.1 (K), R25.1
unnamed: D26.1 (K), R26.1
unnamed: D27.1 (K), R27.1
unnamed: D28.1 (K), R28.1
unnamed: D29.1 (K), R29.1
unnamed: D30.1 (K), R30.1
unnamed: D31.1 (K), R31.1
unnamed: D32.1 (K), R32.1
unnamed: D33.1 (K), R33.1
unnamed: D34.1 (K), R34.1
unnamed: D35.1 (K), R35.1
unnamed: D36.1 (K), R36.1
unnamed: D37.1 (K), R37.1
unnamed: D38.1 (K), R38.1
unnamed: D39.1 (K), R39.1
unnamed: D40.1 (K), R40.1
unnamed: D41.1 (K), R41.1
unnamed: D42.1 (K), R42.1
unnamed: D43.1 (K), R43.1
unnamed: D44.1 (K), R44.1
unnamed: D45.1 (K), R45.1
unnamed: D46.1 (K), R46.1
unnamed: D47.1 (K), R47.1
unnamed: D48.1 (K), R48.1
unnamed: D49.1 (K), R49.1
unnamed: D50.1 (K), R50.1
unnamed: D51.1 (K), R51.1
unnamed: D52.1 (K), R52.1
unnamed: D53.1 (K), R53.1
unnamed: D54.1 (K), R54.1
unnamed: D55.1 (K), R55.1
unnamed: D56.1 (K), R56.1
unnamed: D57.1 (K), R57.1
unnamed: D58.1 (K), R58.1
unnamed: D59.1 (K), R59.1
unnamed: D60.1 (K), R60.1
unnamed: D61.1 (K), R61.1
unnamed: D62.1 (K), R62.1
unnamed: D63.1 (K), R63.1
unnamed: D64.1 (K), R64.1
unnamed: D65.1 (K), R65.1
unnamed: D66.1 (K), R66.1
unnamed: D67.1 (K), R67.1
unnamed: D68.1 (K), R68.1
unnamed: D69.1 (K), R69.1
unnamed: D70.1 (K), R70.1
unnamed: D71.1 (K), R71.1
unnamed: D72.1 (K), R72.1
unnamed: D73.1 (K), R73.1
unnamed: D74.1 (K), R74.1
unnamed: D75.1 (K), R75.1
unnamed: D76.1 (K), R76.1
unnamed: D77.1 (K), R77.1
unnamed: D78.1 (K), R78.1
unnamed: D79.1 (K), R79.1
unnamed: D80.1 (K), R80.1
unnamed: D81.1 (K), R81.1
unnamed: D82.1 (K), R82.1
unnamed: D83.1 (K), R83.1
unnamed: D84.1 (K), R84.1
unnamed: D85.1 (K), R85.1
unnamed: D86.1 (K), R86.1
unnamed: D87.1 (K), R87.1
unnamed: D88.1 (K), R88.1
unnamed: D89.1 (K), R89.1
unnamed: D90.1 (K), R90.1
unnamed: D91.1 (K), R91.1
unnamed: D92.1 (K), R92.1
unnamed: D93.1 (K), R93.1
unnamed: D94.1 (K), R94.1
unnamed: D95.1 (K), R95.1
unnamed: D96.1 (K), R96.1
unnamed: D97.1 (K), R97.1
unnamed: D98.1 (K), R98.1
unnamed: D99.1 (K), R99.1
unnamed: D100.1 (K), R100.1
unnamed: D101.1 (K), R101.1
unnamed: D102.1 (K), R102.1
unnamed: D103.1 (K), R103.1
unnamed: D104.1 (K), R104.1
unnamed: D105.1 (K), R105.1
unnamed: D106.1 (K), R106.1
unnamed: D107.1 (K), R107.1
unnamed: D108.1 (K), R108.1
unnamed: D109.1 (K), R109.1
unnamed: D110.1 (K), R110.1
unnamed: D111.1 (K), R111.1
unnamed: D112.1 (K), R112.1
unnamed: D113.1 (K), R113.1
unnamed: D114.1 (K), R114.1
unnamed: D115.1 (K), R115.1
unnamed: D116.1 (K), R116.1
unnamed: D117.1 (K), R117.1
unnamed: D118.1 (K), R118.1
unnamed: D119.1 (K), R119.1
unnamed: D120.1 (K), R120.1
unnamed: D121.1 (K), R121.1
unnamed: D122.1 (K), R122.1
unnamed: D123.1 (K), R123.1
unnamed: D124.1 (K), R124.1
unnamed: D125.1 (K), R125.1
unnamed: D126.1 (K), R126.1
unnamed: D127.1 (K), R127.1
unnamed: D128.1 (K), R128.1
unnamed: D129.1 (K), R129.1
unnamed: D130.1 (K), R130.1
unnamed: D131.1 (K), R131.1
unnamed: D132.1 (K), R132.1
unnamed: D133.1 (K), R133.1
unnamed: D134.1 (K), R134.1
unnamed: D135.1 (K), R135.1
unnamed: D136.1 (K), R136.1
unnamed: D137.1 (K), R137.1
unnamed: D138.1 (K), R138.1
unnamed: D139.1 (K), R139.1
unnamed: D140.1 (K), R140.1
unnamed: D141.1 (K), R141.1
unnamed: D142.1 (K), R142.1
unnamed: D143.1 (K), R143.1
unnamed: D144.1 (K), R144.1
unnamed: D145.1 (K), R145.1
unnamed: D146.1 (K), R146.1
unnamed: D147.1 (K), R147.1
unnamed: D148.1 (K), R148.1
unnamed: D149.1 (K), R149.1
unnamed: D150.1 (K), R150.1
unnamed: D151.1 (K), R151.1
unnamed: D152.1 (K), R152.1
unnamed: D153.1 (K), R153.1
unnamed: J1.1, U1.6 (GP2)
unnamed: J1.2, U1.7 (GP3)
unnamed: J1.3, U1.8 (GP4)
unnamed: J1.4, U1.9 (GP5)
unnamed: J2.1, U1.10 (GP6)
unnamed: J3.1, U1.4 (GP0), U2.3 (SCL)
unnamed: J3.2, U1.5 (GP1), U2.4 (SDA)
unnamed: Q1.1 (G), R154.1, R157.1
unnamed: Q2.1 (G), R155.1, R158.1
unnamed: Q3.1 (G), R156.1, R159.1
unnamed: R154.2, U1.11 (GP7)
unnamed: R156.2, U1.12 (GP8)
unnamed: R155.2, U1.13 (GP9)

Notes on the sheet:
do not use GP18-21 - very restricted functionality
GP10 in use by onboard WS2812

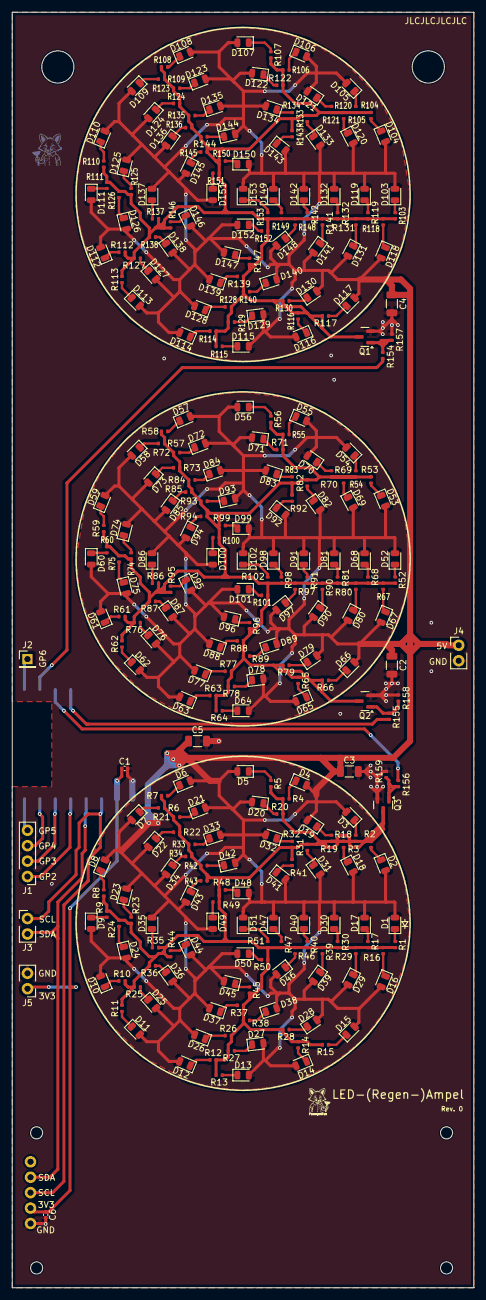
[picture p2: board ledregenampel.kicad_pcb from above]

Board: 2 copper layers, 76.0 x 210.0 mm, 330 parts (1 on the bottom side), 172 nets.

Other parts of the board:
mnthole1, mnthole2: MountingHole_5.3mm_M5

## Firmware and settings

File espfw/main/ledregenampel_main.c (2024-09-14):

/* LED-Regen-Ampel. The main structure of this is stolen from foxesptemp.
 */
#include "sdkconfig.h"
#include <stdio.h>
#include <freertos/FreeRTOS.h>
#include <freertos/task.h>
#include <esp_system.h>
#include <esp_log.h>
#include <driver/gpio.h>
#include <driver/i2c.h>
#include <soc/i2c_reg.h>
#include <time.h>
#include <esp_sntp.h>
#include <nvs_flash.h>
#include <esp_ota_ops.h>
#include <math.h>
#include <esp_netif.h>
#include <sys/time.h>
#include "display.h"
#include "i2c.h"
#include "leds.h"
#include "network.h"
#include "regenampelde.h"
#include "settings.h"
#include "sh1122.h"
#include "webserver.h"

#define sleep_ms(x) vTaskDelay(pdMS_TO_TICKS(x))

/* Global / Exported variables, used to provide the webserver.
 * struct ev is defined in webserver.h for practical reasons. */
struct ev evs[2];
int activeevs = 0;
static const char *TAG = "ledregenampel";

/* Has the firmware been marked as "good" yet, or is ist still pending
 * verification? */
int pendingfwverify = 0;

/* we need this to display our IP, it is in network.c */
extern esp_netif_t * mainnetif;

/* Our main display buffer (we currently only use one) */
struct di_dispbuf * db;

/* Last data received from regenampel.de */
struct rade_data rad = { .light_color = LED_INVALID };

/* regenampel.de updateinterval. We might want to move this to settings? */
int raupdateint = 300;

/* This variable is normally 0. The webserver will set it to something
 * in order to tell us, we need to blink all lights once, because the
 * user clicked 'Test' on the webinterface. */
uint8_t ledoverride = 0;

void app_main(void)
{
    /* This is in all OTA-Update examples, so I consider it mandatory. */
    esp_err_t err = nvs_flash_init();
    if ((err == ESP_ERR_NVS_NO_FREE_PAGES) || (err == ESP_ERR_NVS_NEW_VERSION_FOUND)) {
      ESP_ERROR_CHECK(nvs_flash_erase());
      err = nvs_flash_init();
    }
    ESP_ERROR_CHECK(err);
    /* Load settings from NVRAM */
    settings_hardcode(); /* smuggles in hardcoded settings for testing */
    settings_load();

    /* Already try to start up the network (will happen mostly in the BG) */
    network_prepare();
    network_on(); /* We don't do network_off, we just try to stay connected */

    i2c_port_init();
    sh1122_init();
    leds_init();

    db = di_newdispbuf();
    di_drawtext(db, 10, 30, &font_FreeSansBold21pt, 0xff, "Foxis LED-Regen-Ampel");
    if (1) {
      uint8_t tmps[100];
      const esp_app_desc_t * appd = esp_app_get_description();
      sprintf(tmps, "FW-ver %s",
              appd->version);
      di_drawtext(db, 10, 60, &font_FreeSansBold21pt, 0xff, tmps);
    }
    sh1122_display(db);

    /* Unfortunately, time does not (always) revert to 0 on an
     * esp_restart. So we set all timestamps to "now" instead.
     * We push back lastupdatt so an update attempt is made
     * after about 10 seconds. */
    time_t lastupdatt = time(NULL) - (raupdateint - 10);
    time_t lastupdsuc = time(NULL);

    /* We do NTP to provide useful timestamps in our webserver output. */
    esp_sntp_setoperatingmode(SNTP_OPMODE_POLL);
    esp_sntp_setservername(0, "ntp2.fau.de");
    esp_sntp_setservername(1, "ntp3.fau.de");
    esp_sntp_init();

    /* In case we were OTA-updating, we set this fact in a variable for the
     * webserver. Someone will need to click "Keep this firmware" in the
     * webinterface to mark the updated firmware image as good, otherwise we
     * will roll back to the previous and known working version on the next
     * reset. */
    const esp_partition_t * running = esp_ota_get_running_partition();
    esp_ota_img_states_t ota_state;
    if (esp_ota_get_state_partition(running, &ota_state) == ESP_OK) {
      if (ota_state == ESP_OTA_IMG_PENDING_VERIFY) {
        pendingfwverify = 1;
      }
    }

    /* Start up the webserver */
    webserver_start();

    /* Now shortly flash all 3 lights at a very low
     * brightness so the user can see they are working */
    for (uint8_t bl = 0; bl <= 3; bl++) {
      for (uint8_t i = 0; i <= 2; i++) {
        if (i == bl) {
          leds_setbrightness(i, 20);
        } else {
          leds_setbrightness(i, 0);
        }
      }
      if (bl < 3) { /* no sleep on the last iteration that turns all off */
        sleep_ms(1000);
      }
    }

    /* Wait for up to 7 more seconds to connect to WiFi and get an IP */
    EventBits_t eb = xEventGroupWaitBits(network_event_group,
                                         NETWORK_CONNECTED_BIT,
                                         pdFALSE, pdFALSE,
                                         (7000 / portTICK_PERIOD_MS));
    if ((eb & NETWORK_CONNECTED_BIT) == NETWORK_CONNECTED_BIT) {
      ESP_LOGI("main.c", "Successfully connected to network.");
    } else {
      ESP_LOGW("main.c", "Warning: Could not connect to WiFi. This is probably not good.");
    }
    /* Do we have IPv4 info? Then print that on the display. */
    if (1) {
      di_drawrect(db, 0, 32, 255, 63, -1, 0x00);
      esp_netif_ip_info_t ip_info;
      if (esp_netif_get_ip_info(mainnetif, &ip_info) == ESP_OK) {
        uint8_t tmps[100];
        sprintf(tmps, "IPv4: " IPSTR "/" IPSTR,
                     IP2STR(&ip_info.ip), IP2STR(&ip_info.netmask));
        di_drawtext(db, 10, 60, &font_FreeSansBold21pt, 0xff, tmps);
      } else {
        di_drawtext(db, 10, 60, &font_FreeSansBold21pt, 0xff, "No IPv4 (yet) :(");
      }
      sh1122_display(db);
    }

    /* Now loop, polling regenampel.de every 5 minutes or so. */
    while (1) {
      if (lastupdatt > time(NULL)) { /* This should not be possible, but we've
         * seen time(NULL) temporarily report insane timestamps far in the
         * future - not sure why, possibly after a watchdog reset, but in any
         * case, lets try to work around it: */
        ESP_LOGE(TAG, "Lets do the time warp again: Time jumped backwards - trying to cope.");
        lastupdatt = time(NULL); // We should return to normality on next iteration
      }
      time_t curts = time(NULL);
      if ((curts - lastupdatt) >= raupdateint) {
        lastupdatt = curts;
        int naevs = (activeevs == 0) ? 1 : 0;
        evs[naevs].lastupdatt = lastupdatt;
        ESP_LOGI("main.c", "Trying to update from regenampel.de...");
        struct rade_data nrad;
        if (rade_tryupdate(&nrad) == 0) { // Successful update
          lastupdsuc = curts;
          evs[naevs].lastupdsuc = lastupdsuc;
          rad = nrad;
        } else { // No successful update
          /* Can we still reuse the old data? */
          if ((curts - lastupdsuc) > (2 * raupdateint + 10)) {
            // data is more than 2 update-intervals old, we no longer accept that.
            // So null the data.
            rad.light_color = LED_INVALID;
            strcpy(rad.message1, "No current data :(");
            strcpy(rad.message2, "No current data :(");
          }
        }
        leds_setledon(rad.light_color);
        di_updateoledwith2msgs(db, rad.message1, rad.message2);
        /* invert the display for the second 15 minutes
         * of every half hour to guarantee equal pixel aging */
        sh1122_setinvertmode( ((curts % 1800) > 900) );
        evs[naevs].light_color = rad.light_color;
        strcpy(evs[naevs].message1, rad.message1);
        strcpy(evs[naevs].message2, rad.message2);

        /* Now mark the updated values as the current ones for the webserver */
        activeevs = naevs;

        if ((curts > 900)
         && ((curts - lastupdsuc) > 900)
         && ((curts - lastupdsuc) < 100000)) {
          /* We have been up for at least 15 minutes and not
           * successfully submitted any values in more than
           * 15 minutes (but the timespan isn't ultralong either,
           * which happens when NTP jumps our time).
           * It might be a good idea to reboot. */
          ESP_LOGE(TAG, "No successful update in %lld seconds - about to reboot.", (time(NULL) - lastupdsuc));
          esp_restart();
        }
      }
      if (ledoverride != 0) { // blink all LEDs in sequence.
        if (ledoverride > 3) { ledoverride = 3; }
        leds_setledon(2 - (ledoverride - 1));
        ledoverride--;
        sleep_ms(1000);
        if ((ledoverride == 0) && (rad.light_color != LED_INVALID)) {
          // restore old state so we don't have to wait for next update.
          // This is irrelevant if we're blinking anyways...
          leds_setledon(rad.light_color);
        }
      } else {
        if (rad.light_color == LED_INVALID) { // Blink yellow
          struct timeval ctv;
          gettimeofday(&ctv, NULL);
          if (ctv.tv_usec > 500000) { // later half of a second
            leds_setledon(LED_YELLOW);
          } else { // earlier half of a second
            leds_setledon(0xff);
          }
          /* Only do a short sleep so we can blink */
          sleep_ms(100);
        } else {
          /* Nothing to do but go back to sleep for a second. */
          /* We sadly cannot do meaningful powersaving here if we want the
           * webinterface to be reachable. */
          sleep_ms(1000);
        }
      }
    }
}

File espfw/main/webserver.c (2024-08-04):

#include <driver/gpio.h>
#include <esp_crt_bundle.h>
#include <esp_http_client.h>
#include <esp_http_server.h>
#include <esp_https_ota.h>
#include <esp_log.h>
#include <esp_netif.h>
#include <esp_ota_ops.h>
#include <esp_random.h>
#include <esp_timer.h>
#include <nvs_flash.h>
#include <time.h>
#include "settings.h"
#include "webserver.h"

/* These are in foxesptemp_main.c */
extern struct ev evs[2];
extern int activeevs;
extern int pendingfwverify;
/* This is in network.c */
extern esp_netif_t * mainnetif;
/* _main.c */
extern uint8_t ledoverride;

static int settingshavechanged = 0;

/* How many admins can be logged in at the same time? */
#define MAXADMINLOGINS 3
/* And what is the maximum lifetime of an admin session, in seconds? */
#define MAXTOKENLIFETIME (30 * 60)
struct authtoken {
  time_t ts; /* When this token was handed out */
  uint8_t token[64]; /* the token. Always 63 bytes plus terminating \0 */
};
static struct authtoken liadmins[MAXADMINLOGINS];

/********************************************************
 * Embedded webpages definition. These are mostly       *
 * in external text files, to make editing them more    *
 * convenient.                                          *
 ********************************************************/

extern const uint8_t startp_p1[] asm("_binary_startpage_html_p00_start");
/* The following seems to exist in the autogenerated file, but it's
 * not documented - so lets avoid using it. */
/* extern uint16_t startp_p1_len asm("startpage_html_p00_length"); */

extern const uint8_t startp_p2[] asm("_binary_startpage_html_p01_start");

extern const uint8_t startpagejs[] asm("_binary_startpage_js_min_start");

extern const uint8_t csscss[] asm("_binary_css_css_min_start");

extern const uint8_t adminmenu_p1[] asm("_binary_adminmenu_html_p00_start");

extern const uint8_t adminmenu_p2[] asm("_binary_adminmenu_html_p01_start");

extern const uint8_t adminmenu_p3[] asm("_binary_adminmenu_html_p02_start");

static const uint8_t adminmenu_fww[] = R"EOAMFWW(
<br><b>A new firmware has been flashed,</b> and booted up (it's currently
running) - <b>but it has not been marked as &quot;good&quot; yet</b>.
Unless you mark the new firmware as &quot;good&quot;, on the next reset the old
firmware will be restored.<br>
<form action="adminaction" method="POST">
<input type="hidden" name="action" value="markfwasgood">
<input type="submit" name="su" value="Mark Firmware as Good"><br>
</form><br>
)EOAMFWW";

static const uint8_t pleaseloginfirstmsg[] = R"EOPLF(
You need to <a href="./#adminloginform">log in</a> before you can
access admin functions.
)EOPLF";

/********************************************************
 * End of embedded webpages definition                  *
 ********************************************************/

/* Helper functions */

/* Unescapes a x-www-form-urlencoded string.
 * Modifies the string inplace!
 * This is a mess that was quickly cobbled together. It
 * purposely excludes certain characters like " and ',
 * because we know all too well that we will print these
 * into html tags unescaped, and that would break with
 * these chars. We should at some time fix this by
 * using proper unescape AND escape functions, but for
 * now it's good enough for a tiny microcontroller. */
void unescapeuestring(uint8_t * s) {
  uint8_t * rp = s;
  uint8_t * wp = s;
  while (*rp != 0) {
    if (strncmp(rp, "+", 1) == 0) {
      *wp = ' '; wp++; rp++;
    } else if (strncmp(rp, "&amp;", 5) == 0) {
      *wp = '&'; rp += 5; wp += 1;
    } else if (strncmp(rp, "%20", 3) == 0) {
      *wp = ' '; rp += 3; wp += 1;
    } else if (strncmp(rp, "%21", 3) == 0) {
      *wp = '!'; rp += 3; wp += 1;
    } else if (strncmp(rp, "%23", 3) == 0) {
      *wp = '#'; rp += 3; wp += 1;
    } else if (strncmp(rp, "%24", 3) == 0) {
      *wp = '$'; rp += 3; wp += 1;
    } else if (strncmp(rp, "%25", 3) == 0) {
      *wp = '%'; rp += 3; wp += 1;
    } else if (strncmp(rp, "%26", 3) == 0) {
      *wp = '&'; rp += 3; wp += 1;
    } else if (strncmp(rp, "%28", 3) == 0) {
      *wp = '('; rp += 3; wp += 1;
    } else if (strncmp(rp, "%29", 3) == 0) {
      *wp = ')'; rp += 3; wp += 1;
    } else if (strncmp(rp, "%2A", 3) == 0) {
      *wp = '*'; rp += 3; wp += 1;
    } else if (strncmp(rp, "%2B", 3) == 0) {
      *wp = '+'; rp += 3; wp += 1;
    } else if (strncmp(rp, "%2C", 3) == 0) {
      *wp = ','; rp += 3; wp += 1;
    } else if (strncmp(rp, "%2D", 3) == 0) {
      *wp = '-'; rp += 3; wp += 1;
    } else if (strncmp(rp, "%2E", 3) == 0) {
      *wp = '.'; rp += 3; wp += 1;
    } else if (strncmp(rp, "%2F", 3) == 0) {
      *wp = '/'; rp += 3; wp += 1;
    } else if (strncmp(rp, "%3A", 3) == 0) {
      *wp = ':'; rp += 3; wp += 1;
    } else if (strncmp(rp, "%3B", 3) == 0) {
      *wp = ';'; rp += 3; wp += 1;
    } else if (strncmp(rp, "%3D", 3) == 0) {
      *wp = '='; rp += 3; wp += 1;
    } else if (strncmp(rp, "%3F", 3) == 0) {
      *wp = '?'; rp += 3; wp += 1;
    } else if (strncmp(rp, "%40", 3) == 0) {
      *wp = '@'; rp += 3; wp += 1;
    } else if (strncmp(rp, "%5B", 3) == 0) {
      *wp = '['; rp += 3; wp += 1;
    } else if (strncmp(rp, "%5D", 3) == 0) {
      *wp = ']'; rp += 3; wp += 1;
    } else if (strncmp(rp, "%5E", 3) == 0) {
      *wp = '^'; rp += 3; wp += 1;
    } else if (strncmp(rp, "%5F", 3) == 0) {
      *wp = '_'; rp += 3; wp += 1;
    } else if (strncmp(rp, "%7E", 3) == 0) {
      *wp = '~'; rp += 3; wp += 1;
    } else {
      *wp = *rp; wp++; rp++;
    }
  }
  *wp = 0;
}

/* Expires auth tokens. Those that have exceeded MAXTOKENLIFETIME will be
 * removed from the list. */
void expireauthtokens() {
  for (int i = 0; i < MAXADMINLOGINS; i++) {
    if ((liadmins[i].ts + MAXTOKENLIFETIME) < time(NULL)) {
      liadmins[i].ts = 0;
      strcpy(liadmins[i].token, "");
    }
  }
}

static const uint8_t tokchars[] = "ABCDEFGHIJKLMNOPQRSTUVWXYZabcdefghijklmnopqrstuvwxyz0123456789";

/* Creates a new entry in the list of logged in admins (liadmins[]).
 * If there is no space, one of the oldest entries will be overwritten, thereby
 * invalidating the session using it.
 * Returns a pointer to the generated new token - as it points to the entry in
 * liadmins[], it naturally must not be modified outside of this function. */
uint8_t * createnewauthtoken(void) {
  expireauthtokens();
  int selectedslot = 0;
  time_t mints = 0;
  for (int i = 0; i < MAXADMINLOGINS; i++) {
    if (liadmins[i].ts < mints) {
      selectedslot = i;
    }
  }
  liadmins[selectedslot].ts = time(NULL);
  for (int i = 0; i < 63; i++) {
    liadmins[selectedslot].token[i] = tokchars[esp_random() % strlen(tokchars)];
  }
  liadmins[selectedslot].token[63] = 0;
  return &(liadmins[selectedslot].token[0]);
}
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

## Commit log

2024-06-30 first of three lights (green) is done.
    [ledregenampel.kicad_pcb, ledregenampel.kicad_sch]
2024-07-06 lets call this RC1
    [ledregenampel.kicad_pcb, ledregenampel.kicad_sch]
2024-07-08 mostly more labelling
    [ledregenampel.kicad_pcb, ledregenampel.kicad_sch]
2024-07-08 add jlcpcb production files
    [BOM-ledregenampel.csv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]
2024-07-12 final rev. 0 as ordered from JLCPCB.
    [ledregenampel.kicad_pcb]
2024-07-14 initial checkin for firmware: mostly an empty hull.
    [partitions.csv]
2024-07-14 clock down CPU and enable some other powermanagement, but unfortunately the ESP32-C3 still gets very hot - most power is probably used by the WiFi.
2024-07-17 support for controlling the leds, including being able to set the PWM brightness per channel through the admin-webinterface.
2024-07-18 expose the leds_setbrightness function and clarify comments.
2024-07-22 big progress - we now query the regenampel-augmented-api, and we show the correct light color.
    [ledregenampel_main.c, webserver.c]
2024-07-27 Make the holes for connecting the display bigger. the display pins barely got through, they were no fun to solder. Lets avoid that problem in a possible future revision.
    [ledregenampel.kicad_pcb]
2024-07-27 implement support for our OLED display. doesn't display anything useful yet, but works.
    [i2c.c, ledregenampel_main.c, sh1122.c]
2024-07-27 show messages on the webpage and on the OLED. OLED-messages are cut off because we're currently doing just two lines with a very large font, we'll be changing that.
2024-07-28 switch our font system to use structures compatible with adafruit_gfx. the main reason for that is that this permits us to reuse their fontconverter with minor modifications, so I don't have to reinv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
    [ledregenampel_main.c, sh1122.c]
2024-08-01 add hint about programming the ESP32-C3
2024-08-01 try to update 10 seconds after booting up, and implement blinking yellow when no (current) data is available.
2024-08-04 implement "test" mode for LED brightness settings (settings are applied instantly, but not save to flash).
2024-09-14 flash all LEDs at very low brightness, and show firmware-version/IP on boot.
